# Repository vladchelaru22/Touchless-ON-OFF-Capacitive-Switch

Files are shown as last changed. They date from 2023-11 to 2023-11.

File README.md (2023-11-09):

# Touchless-ON-OFF-Capacitive-Switch
College Project made during CAD Circuit Design class.

Using a given set of parameters, a physical circuit and schematic, I translated the circuit into an OrCAD schematic and produced PCB Design of the circuit using both SMT and THT - using either common PCB Footprints or creating some of my own
Exported the electrical and mechanical layers, with their respective Gerber files, making the project ready to print and fabricate.

Additional information is found in the PDF File (Originally in Romanian-Translation Needed).

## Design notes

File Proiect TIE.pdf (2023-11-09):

## UNIVERSITATEA ,,POLITEHNICA” DIN BUCUREȘTI

Facultatea de Electronică, Telecomunicații și Tehnologia Informației

## Proiect P3 TIE

## Touchless ON/OFF Human Interface Capacitive Switch

DEPARTAMENTUL DE ELECTRONICĂ ȘI TEHNICI DE INTERCONECTARE

Profesor Coordonator:

Prof. Dr. Ing. Norocel Dragoș Codreanu

Echipa T2, studenți:

Cîrstea Georgian-Cristian – Project Manager

Chelaru Vlad-Andrei

Didiță Ana-Maria

An universitar 2022-2023

Dată de predare: 06.09.2023

## CUPRINS

I. DATE INIȚIALE DE PROIECTARE | 3
I.1 Descrierea funcționării schemei proiectate | 4
I.2 Schema electrică | 5
I.3 Design Rules Check(DRC) | 6
I.4 Cross Reference(CR) | 7
I.5 Bill of materials(BOM) | 8
I.6 Wirelist(WR) | 10
I.7 Prezentarea corelației dintre anexa 1 şi proiectul CAD generat | 12
II. PROIECTARE CIRCUIT IMPRIMAT(LAYOUT) - PCB | 13
II.1 Layer-ul TOP | 13
II.2 Layer-ul BOTTOM | 14
II.3 Layer-ul SOLDER MASK TOP | 15
II.4 Layer-ul SOLDER MASK BOTTOM | 16
II.5 Layer-ul SILK SCREEN TOP | 17
II.6 Layer-ul ASSEMBLY DRAWING TOP | 18
III. PROIECTARE MECANICĂ - MECH | 19
III.1 Layer-ul FABRICATION | 19
IV. CONCLUZII | 20
V. BIBLIOGRAFIE/WEBOGRAFIE | 21
VI. ANEXE | 20

# I.Date inițiale de proiectare

Scopul proiectului constă în realizarea design-ului PCB al unui comutator capacitiv ON/OFF fără atingere, conform unei scheme electrice și a unor parametrii dați. O poartă SAU negat 74HC02 acționează ca un senzor capacitiv de mare impedanță. Aceasta setează sau resetează un circuit de blocare și acționează un LED și un releu electromagnetic pentru controlul de înaltă putere. Simpla plasare a unui deget lângă pad este suficientă pentru a comuta latch-ul. Astfel, nu este necesar niciun contact uman, iar pad-ul poate fi izolat. O rază de 15mm este ușor de obținut și sensibilitatea este reglabilă. Alimentarea este furnizată printr-o sursă de 12VDC.

Proiectul PCB va fi realizat utilizând numai două straturi electrice, cele externe: TOP și BOTTOM, toate componentele fiind plasate pe layerul superior al plăcii, TOP. Vor fi folosite și următoarele layer-e neelectrice: SOLDER MASK pentru ambele fețe ale plăcii, SILK SCREEN TOP și ASSEMBLY DRAWING TOP. Lățimea traseelor de semnal va fi de 0.3mm, conexiunea cu masa va fi realizată printr-un plan de masă pe stratul BOTTOM, lățimea traseelor de masă/ alimentare fiind de 1.1mm, iar spațierea va fi de 0.35mm în toate cazurile. Placa va avea formă dreptunghiulară, cu dimensiunile 70x55mm. Cele 4 găuri de prindere a modulului PCB în carcasă vor fi nemetalizate, de 3.2mm diametru, plasate în cele 4 colțuri, la o distanță de 1.5M față de acestea. Aceste specificații și valori de proiectare sunt menționate și in ANEXA 2, pe rândul corespunzător echipei cu numărul 2.

Schema electrică echivalentă în programul OrCAD Capture(va fi prezentată și la sfârșit, în ANEXA 1):

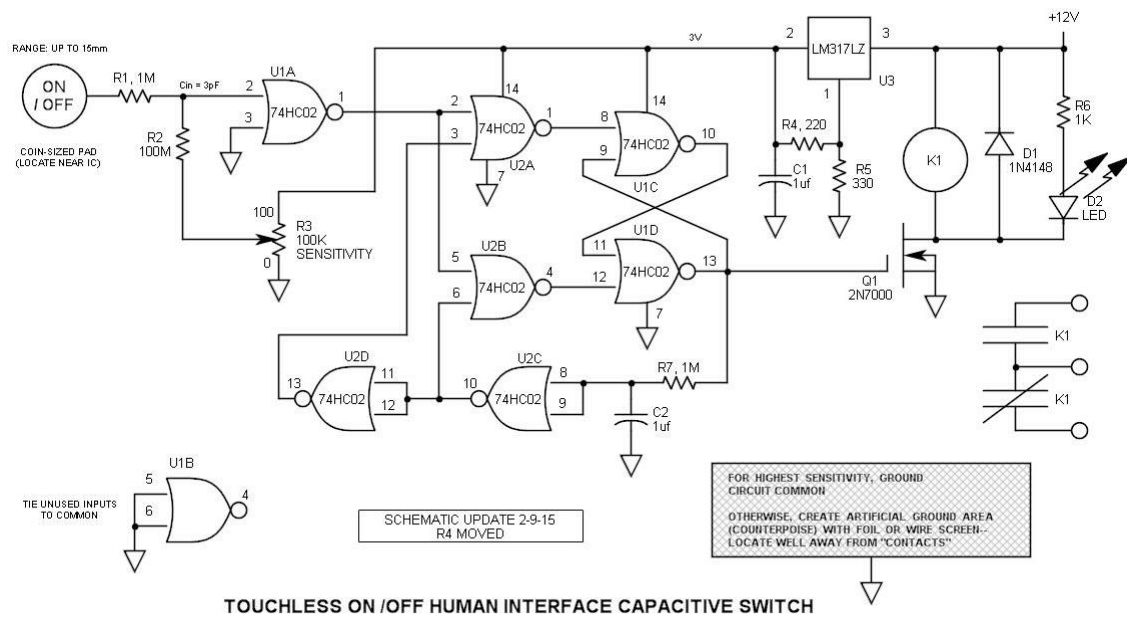
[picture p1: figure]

# I.1 Descrierea funcționării schemei proiectate

Poarta SAU negat 74HC02 acționează ca un senzor capacitiv de mare impedanță, capacitatea de intrare a acesteia fiind de obicei de numai 3pF. Pentru a face acest senzor foarte sensibil la capacitatea corpului este recomandată utilizarea unui resistor de polarizare de 100M.

Sensibilitatea este crescută prin reducerea tensiunii de alimentare la 3V (tensiunea minimă de funcționare specificată fiind de 2.0V). Plasarea unui deget lângă pad este suficientă pentru a comuta latch-ul, nefiind necesar vreun contact uman. Pad-ul, în acest caz, este un ban lipit la un rezistor de 1M. După ce latch-ul este setat sau resetat, condensatorul C2 se încarcă sau se descarcă prin R7. Când se atinge pragul (Vcc/2), porțile U2A și U2B redirecționează semnalul de intrare către intrarea opusă a latch-ului.

Tranzistorul MOS 2N7000 cu canal N (Q1) conduce un curent de 20mA la LED-ul ultraluminos si o tensiune de 12V la releu. Rezistorul de 1M de la intrare protejează circuitul integrat împotriva descărcărilor statice și permite atingerea plăcuței fără pericol de deteriorare prin descărcare electrostatică.

Una dintre problemele apărute pe parcursul evoluției circuitului a fost localizarea porții U2C în U1 din cauza oscilării bruște a U2C când a trecut pragul, generând o perturbare electrică ce a dus la funcționarea defectuoasă a circuitului. De asemenea, o altă problemă a constat în faptul că una dintre intrările porții era deteriorate, probabil din cauza unor descărcări electrostatice, ceea ce împiedicat funcționarea cu impedanță mare.

Cu cât sensibilitatea potențiometrului este mai aproape de prag, cu atât există șanse mai mari ca o perturbare electrostatică sau electromagnetică să provoace accidental schimbări de stare.

## I.2 Schema electrică

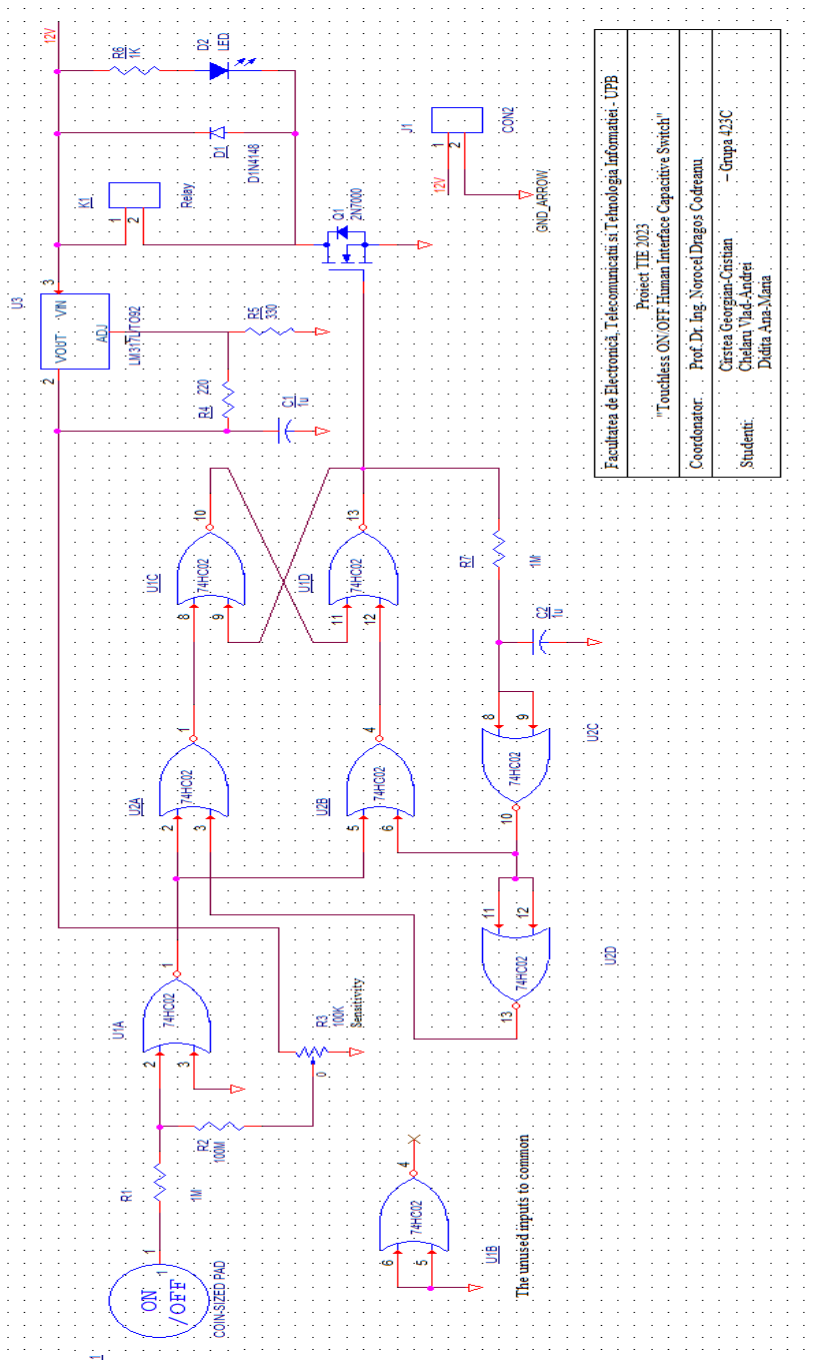
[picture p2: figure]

## I.3 Design Rules Check(DRC)

Date and Time : 09/02/23 17:36:44

Checking Schematic: SCHEMATIC1

Checking Electrical Rules

Checking For Single Node Nets

Checking For Unconnected Bus Nets

## I.4 Cross Reference(CR)

1 | 1K | R6 | SCHEMATIC1/PAGE1 | 0
D:\ORCAD\TOOLS\CAPTURE\LIBRARY\DISCRETE.OLB
2 | 1M | R1 | SCHEMATIC1/PAGE1 | 0
D:\ORCAD\TOOLS\CAPTURE\LIBRARY\DISCRETE.OLB
3 | 1M | R7 | SCHEMATIC1/PAGE1 | 0
D:\ORCAD\TOOLS\CAPTURE\LIBRARY\DISCRETE.OLB
4 | 1u | C1 | SCHEMATIC1/PAGE1 | 0
D:\ORCAD\TOOLS\CAPTURE\LIBRARY\DISCRETE.OLB
5 | 1u | C2 | SCHEMATIC1/PAGE1 | 0
D:\ORCAD\TOOLS\CAPTURE\LIBRARY\DISCRETE.OLB
6 | 2N7000 Q1 | SCHEMATIC1/PAGE1 | 0
D:\ORCAD\TOOLS\CAPTURE\LIBRARY\TRANSISTOR.OLB
7 | 74HC02 U1A | SCHEMATIC1/PAGE1 | 0 | C:\USERS\VLADC\DESKTOP\PROIECT TIE 2023 -
ECHIPA 2 - 423C\CIRCUIT (SCHEMATIC+PCB)\HUMAN_INTERFACE_CAPACITIVE_SWITCH-SCHEMATIC.DSN
8 | 74HC02 U1B | SCHEMATIC1/PAGE1 | 0 | C:\USERS\VLADC\DESKTOP\PROIECT TIE 2023 -
ECHIPA 2 - 423C\CIRCUIT (SCHEMATIC+PCB)\HUMAN_INTERFACE_CAPACITIVE_SWITCH-SCHEMATIC.DSN
9 | 74HC02 U1C | SCHEMATIC1/PAGE1 | 0 | C:\USERS\VLADC\DESKTOP\PROIECT TIE 2023 -
ECHIPA 2 - 423C\CIRCUIT (SCHEMATIC+PCB)\HUMAN_INTERFACE_CAPACITIVE_SWITCH-SCHEMATIC.DSN
10 | 74HC02 U1D | SCHEMATIC1/PAGE1 | 0 | C:\USERS\VLADC\DESKTOP\PROIECT TIE 2023 -
ECHIPA 2 - 423C\CIRCUIT (SCHEMATIC+PCB)\HUMAN_INTERFACE_CAPACITIVE_SWITCH-SCHEMATIC.DSN
11 | 74HC02 U2A | SCHEMATIC1/PAGE1 | 0 | C:\USERS\VLADC\DESKTOP\PROIECT TIE 2023 -
ECHIPA 2 - 423C\CIRCUIT (SCHEMATIC+PCB)\HUMAN_INTERFACE_CAPACITIVE_SWITCH-SCHEMATIC.DSN
12 | 74HC02 U2B | SCHEMATIC1/PAGE1 | 0 | C:\USERS\VLADC\DESKTOP\PROIECT TIE 2023 -
ECHIPA 2 - 423C\CIRCUIT (SCHEMATIC+PCB)\HUMAN_INTERFACE_CAPACITIVE_SWITCH-SCHEMATIC.DSN
13 | 74HC02 U2C | SCHEMATIC1/PAGE1 | 0 | C:\USERS\VLADC\DESKTOP\PROIECT TIE 2023 -
ECHIPA 2 - 423C\CIRCUIT (SCHEMATIC+PCB)\HUMAN_INTERFACE_CAPACITIVE_SWITCH-SCHEMATIC.DSN
14 | 74HC02 U2D | SCHEMATIC1/PAGE1 | 0 | C:\USERS\VLADC\DESKTOP\PROIECT TIE 2023 -
ECHIPA 2 - 423C\CIRCUIT (SCHEMATIC+PCB)\HUMAN_INTERFACE_CAPACITIVE_SWITCH-SCHEMATIC.DSN
15 | 100K | R3 | SCHEMATIC1/PAGE1 | 0
D:\ORCAD\TOOLS\CAPTURE\LIBRARY\PSPICE\BREAKOUT.OLB
16 | 100M | R2 | SCHEMATIC1/PAGE1 | 0
D:\ORCAD\TOOLS\CAPTURE\LIBRARY\DISCRETE.OLB
17 | 220 | R4 | SCHEMATIC1/PAGE1 | 0
D:\ORCAD\TOOLS\CAPTURE\LIBRARY\DISCRETE.OLB
18 | 330 | R5 | SCHEMATIC1/PAGE1 | 0
D:\ORCAD\TOOLS\CAPTURE\LIBRARY\DISCRETE.OLB
19 | COIN-SIZED PAD 1 | SCHEMATIC1/PAGE1 | 0 | C:\USERS\VLADC\DESKTOP\PROIECT
TIE-HUMAN INTERFACE CAPACITIVE SWITCH\HUMAN_INTERFACE_CAPACITIVE_SWITCH-SCHEMATIC.DSN
20 | CON2 | J1 | SCHEMATIC1/PAGE1 | 0 | C:\USERS\VLADC\DESKTOP\PROIECT TIE 2023 -
ECHIPA 2 - 423C\CIRCUIT (SCHEMATIC+PCB)\HUMAN_INTERFACE_CAPACITIVE_SWITCH-SCHEMATIC.DSN
21 | D1N4148D1 | SCHEMATIC1/PAGE1 | 0
D:\ORCAD\TOOLS\CAPTURE\LIBRARY\PSPICE\EDIODE.OLB
22 | LED | D2 | SCHEMATIC1/PAGE1 | 0
D:\ORCAD\TOOLS\CAPTURE\LIBRARY\DISCRETE.OLB
23 | LM317L/TO92 | U3 | SCHEMATIC1/PAGE1 | 0 | C:\USERS\VLADC\DESKTOP\PROIECT
TIE 2023 - ECHIPA 2 - 423C\CIRCUIT (SCHEMATIC+PCB)\HUMAN_INTERFACE_CAPACITIVE_SWITCH-SCHEMATIC.DSN
24 | Relay | K1 | SCHEMATIC1/PAGE1 | 0
D:\ORCAD\TOOLS\CAPTURE\LIBRARY\CONNECTOR.OLB

I.5 Bill Of Materials(BOM) | Pret total: 56.55 lei

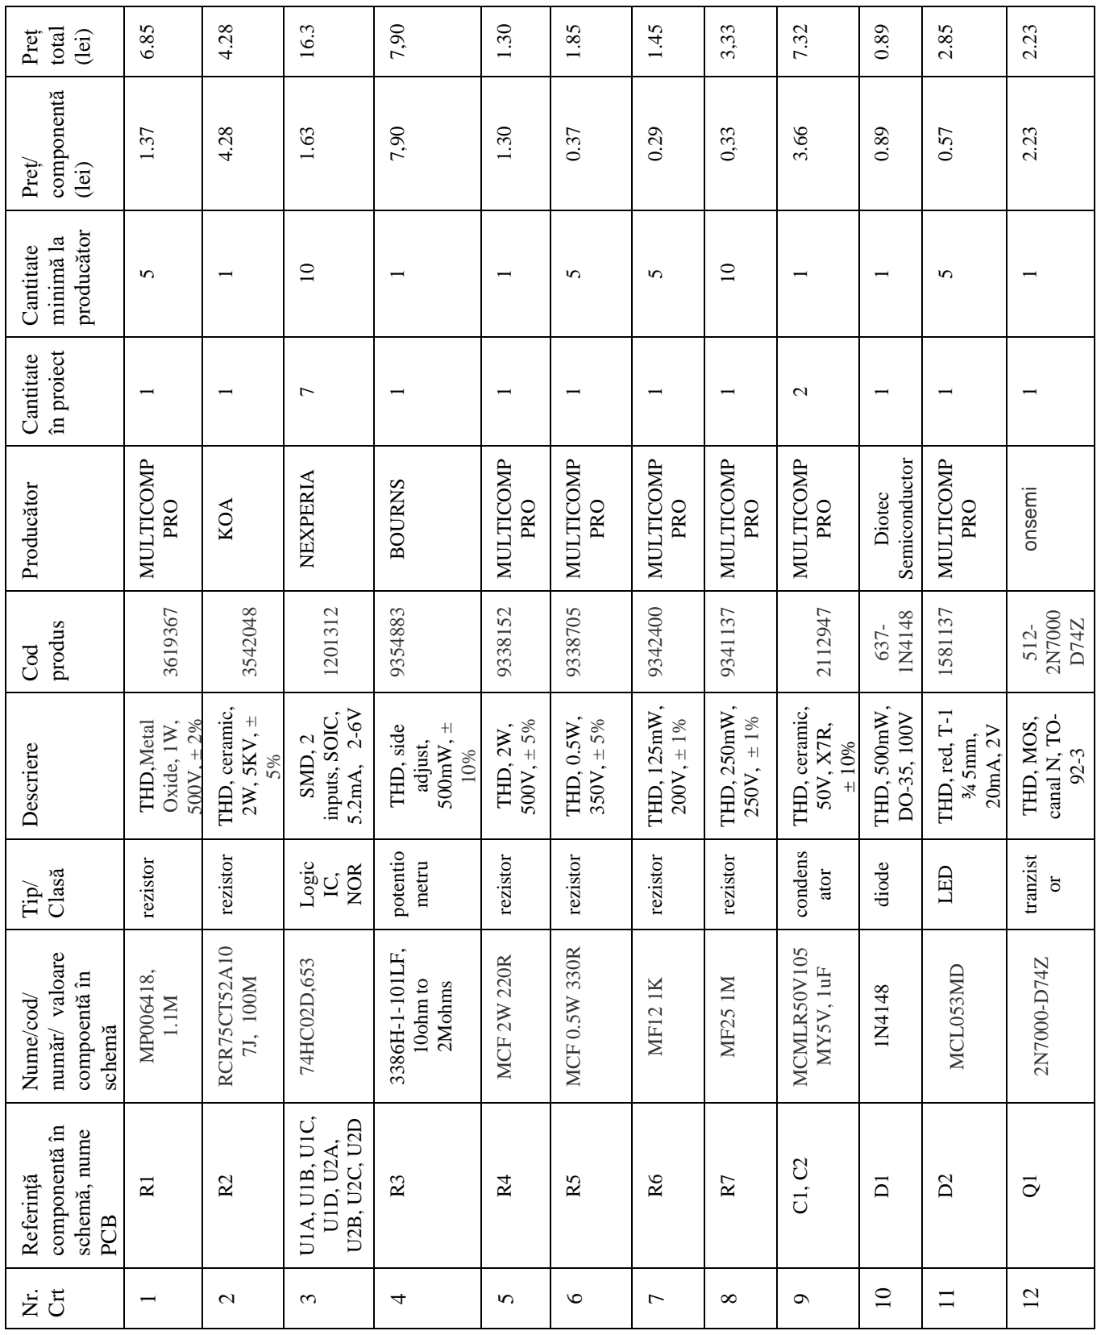
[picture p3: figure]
Preț; total; (lei); Preț/; componentă; Cantitate; minimă la; producător; în proiect; Producător; MULTICOMP; PRO; KOA; NEXPERIA; BOURNS; Diotec; Semiconductor; onsemi; Cod; produs; Descriere; THD,Metal; Oxide, 1W,; THD, ceramic,; SMD, 2; inputs, SOIC,; THD, side; adjust,; THD, 2W,; THD, 0.5W,; THD, 125mW,; THD, 250mW,; THD, 500mW,; THD, red, T-1; THD, MOS,; canal N, TO- 92-3; Tip/; Clasă; rezistor; Logic; NOR; gate; potentio; metru; condens; ator; diode; LED; tranzist; Nume/cod/; număr/ valoare; compoentă în; schemă; RCR75CT52A10; 10ohm to; 2Mohms; MCF 2W 220R; MCF 0.5W 330R; MCMLR50V105; MCL053MD; Referinţă; componentă în; schemă, nume; PCB; Crt

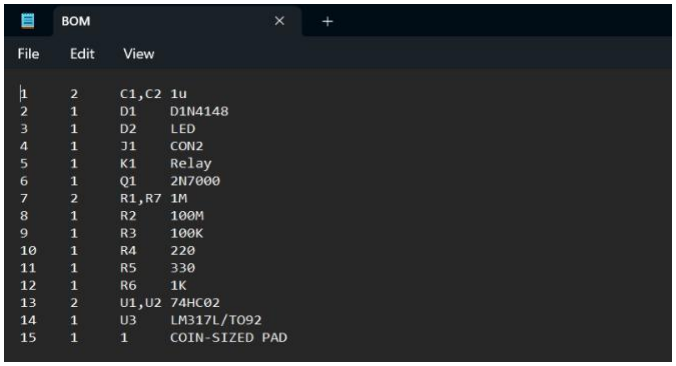
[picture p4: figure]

1 | 2 | C1,C2 1u
2 | 1 | D1 | D1N4148
3 | 1 | D2 | LED
4 | 1 | J1 | CON2
5 | 1 | K1 | Relay
6 | 1 | Q1 | 2N7000
7 | 2 | R1,R7 1M
8 | 1 | R2 | 100M
9 | 1 | R3 | 100K
10 | 1 | R4 | 220
11 | 1 | R5 | 330
12 | 1 | R6 | 1K
13 | 2 | U1,U2 74HC02
14 | 1 | U3 | LM317L/TO92
15 | 1 | 1 | COIN-SIZED PAD

## I.6 Wirelist(WR)

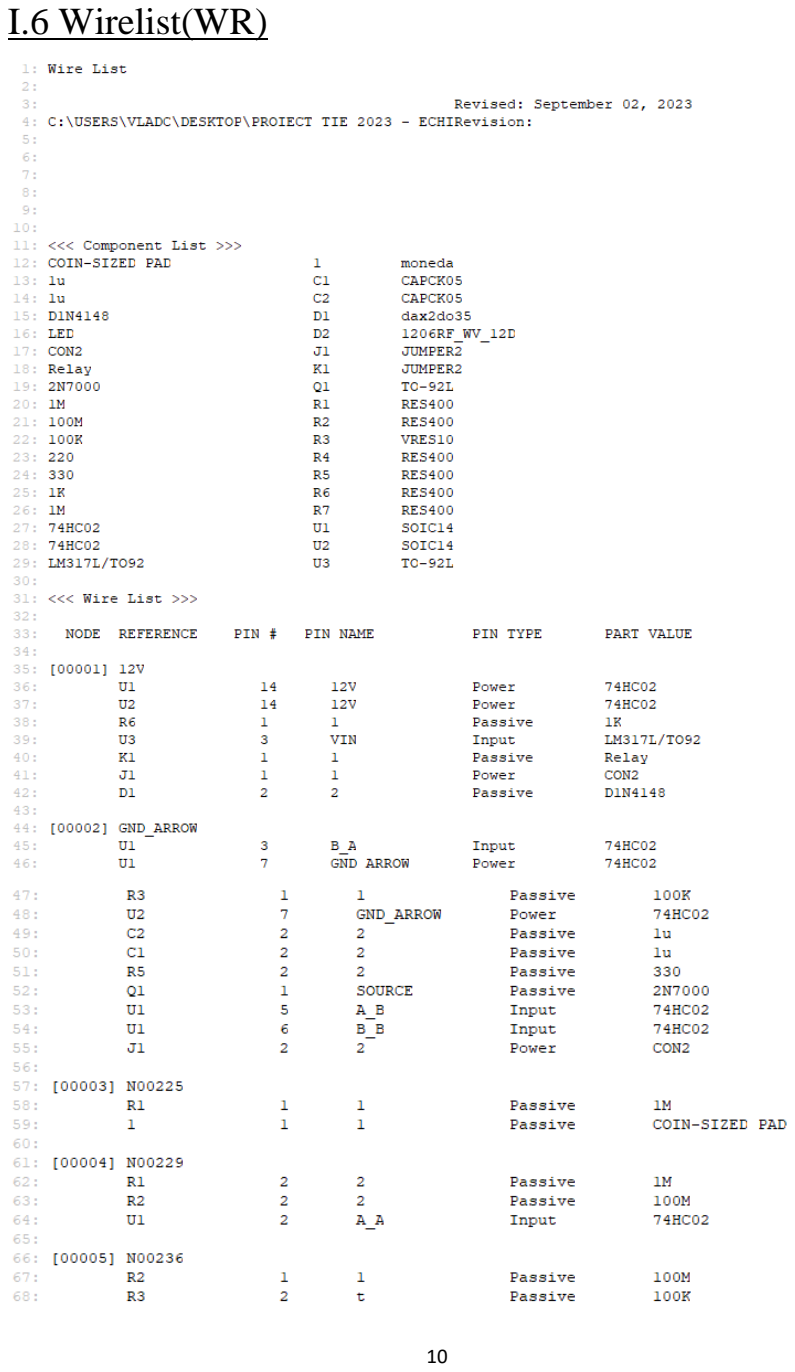
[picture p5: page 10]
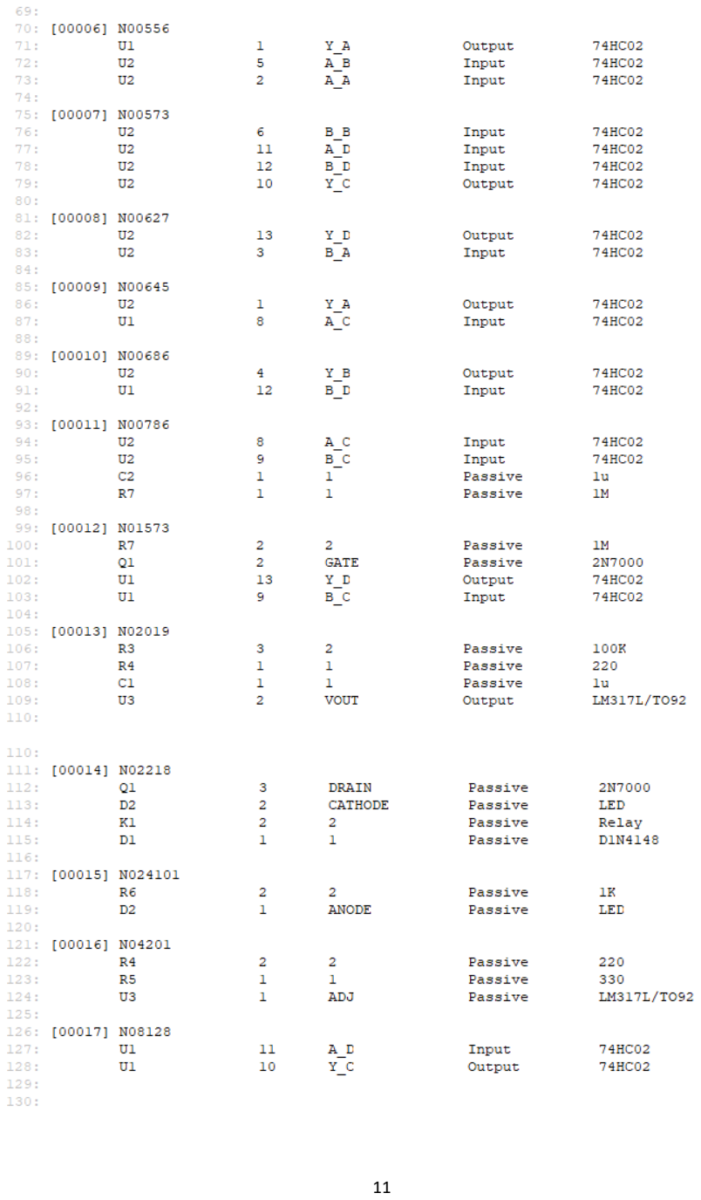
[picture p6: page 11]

## I.7 Prezentarea corelației dintre anexa 1 şi proiectul CAD generat

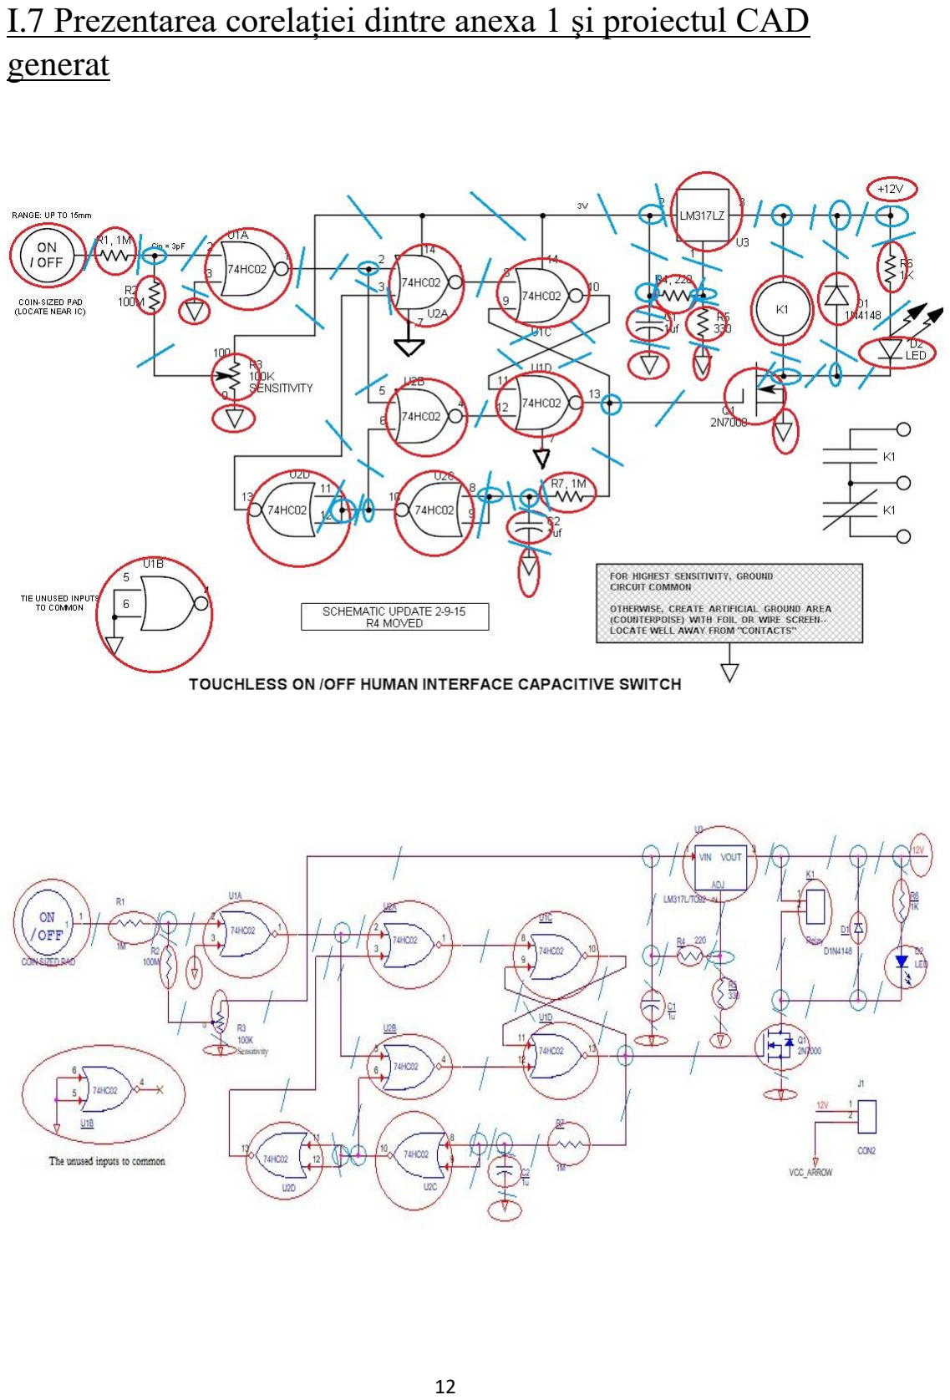
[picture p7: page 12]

# II. PROIECTARE CIRCUIT IMPRIMAT(LAYOUT) – PCB

## II.1 Layer-ul TOP

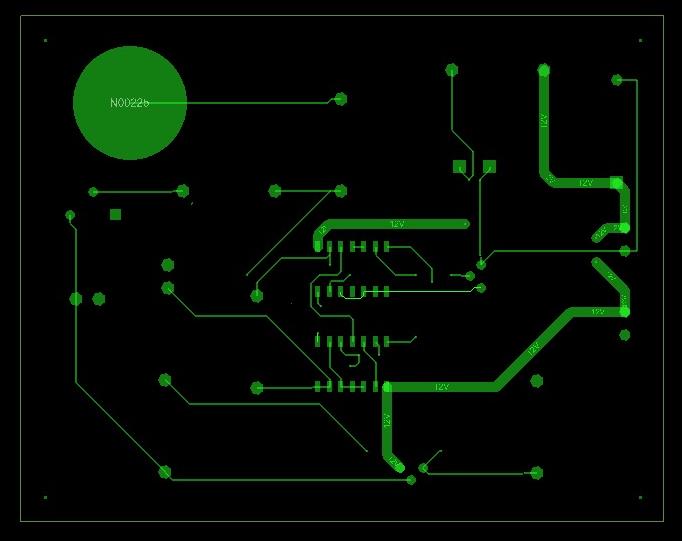
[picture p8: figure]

## II.2 Layer-ul BOTTOM

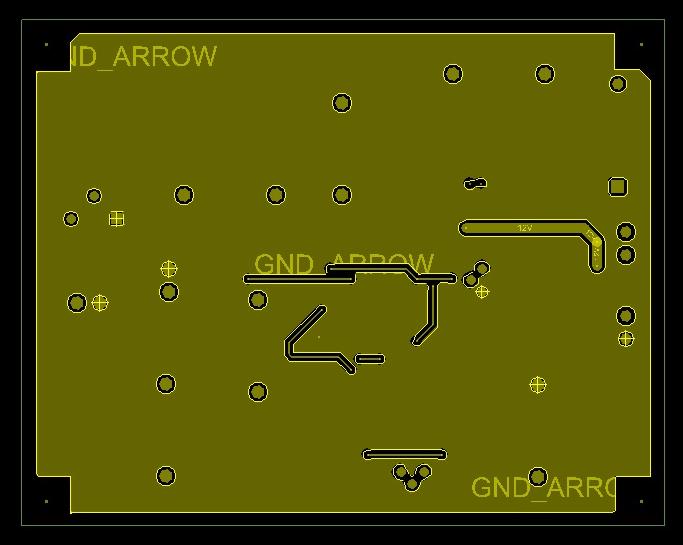
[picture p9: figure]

## II.3 Layer-ul SOLDER MASK TOP

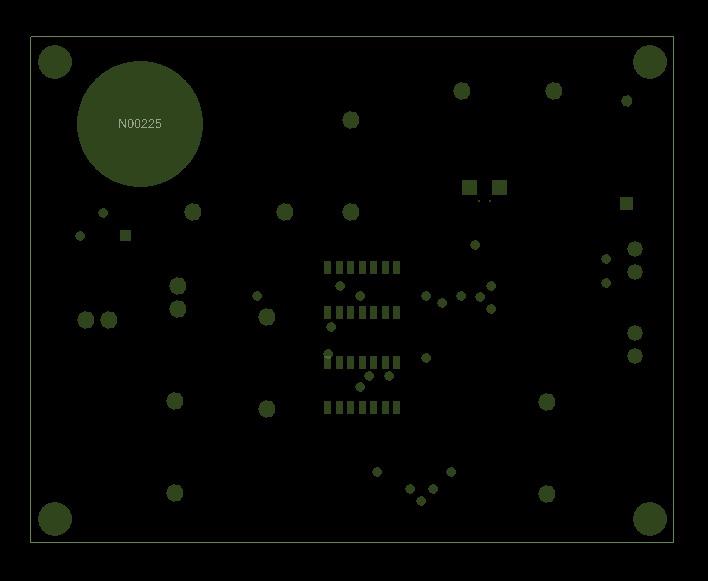
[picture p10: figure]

## II.4 Layer-ul SOLDER MASK BOTTOM

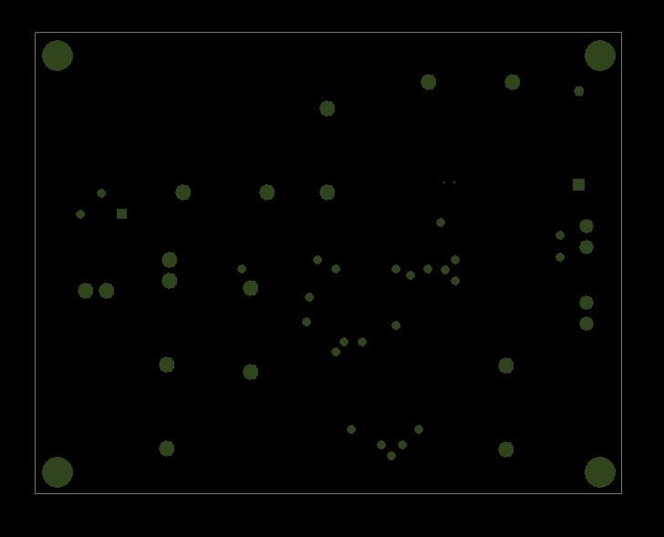
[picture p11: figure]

## II.5 Layer-ul SILK SCREEN TOP

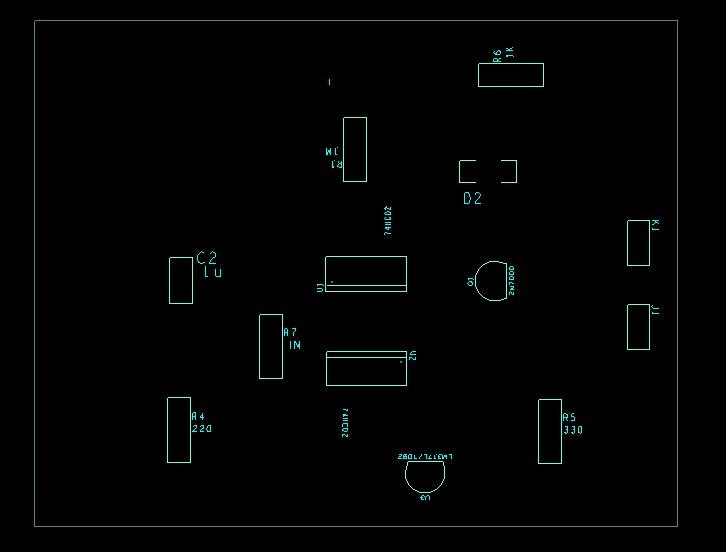
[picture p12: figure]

## II.6 Layer-ul ASSEMBLY DRAWING TOP

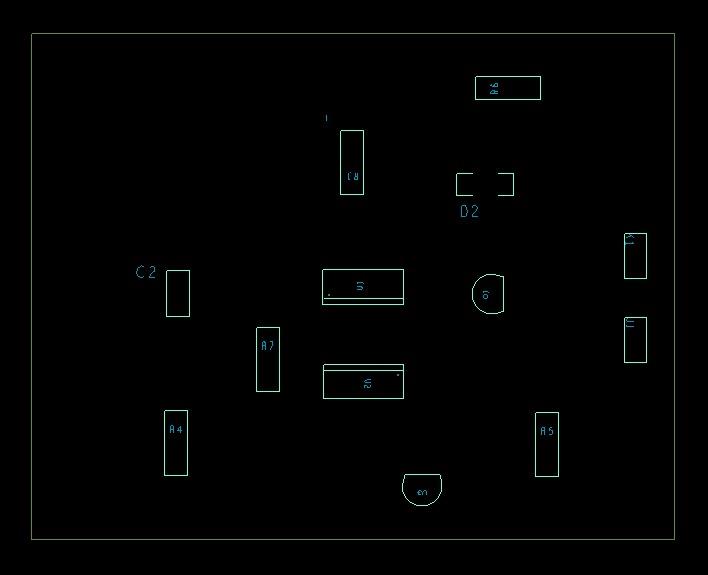
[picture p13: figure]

# III. PROIECTARE MECANICĂ - MERCH

## III.1 Layer-ul FABRICATION

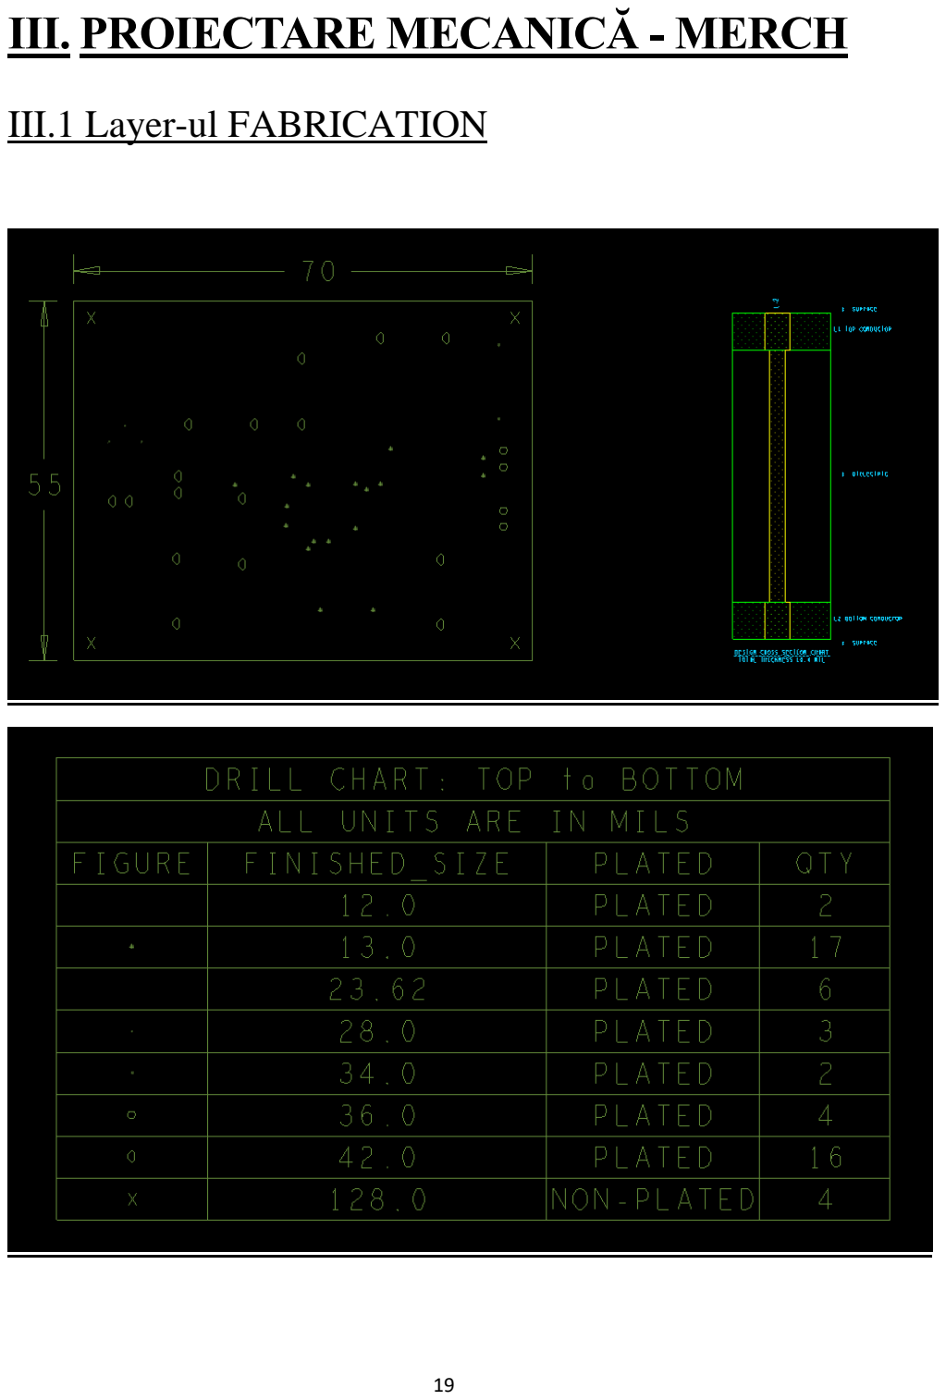
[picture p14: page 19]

# IV. CONCLUZII

Pentru proiectarea structurii schematice a acestui modul electronic a fost utilizat programul OrCAD 17.2 Lite, iar elaborarea design-ului PCB a fost realizată prin intermediul programului OrCAD PCB Editor. Deși acestea ne oferă o multitudine de facilități în realizarea, verificarea si simularea diverselor scheme electrice, este necesară și atenția la detalii pentru a efectua toate operațiile necesare procesării, fără a întâmpina defecte de proiectare ce duc la funcționarea defectuoasă a circuitului. Prin înțelegerea funcționalității schemei ce urmează a fi proiectată se pot evita aceste erori, se pot reduce costurile suplimentare și se poate economisi timp.

Realizarea acestei lucrări ne-a oferit posibilitatea de a înțelege importanța proiectării PCB, reușind să căpătăm cunoștințele și abilitățile de bază absolut necesare pe care trebuie să le îndeplinească un proiectant de success.

# V. BIBLIOGRAFIE/WEBOGRAFIE

1. https://www.electroschematics.com/touchless-on-off-capacitive-switch/
2. https://youtu.be/mjoHTE26fHQ
3. https://ro.farnell.com/
4. https://ro.mouser.com/

# VI. ANEXE

## ANEXA 1

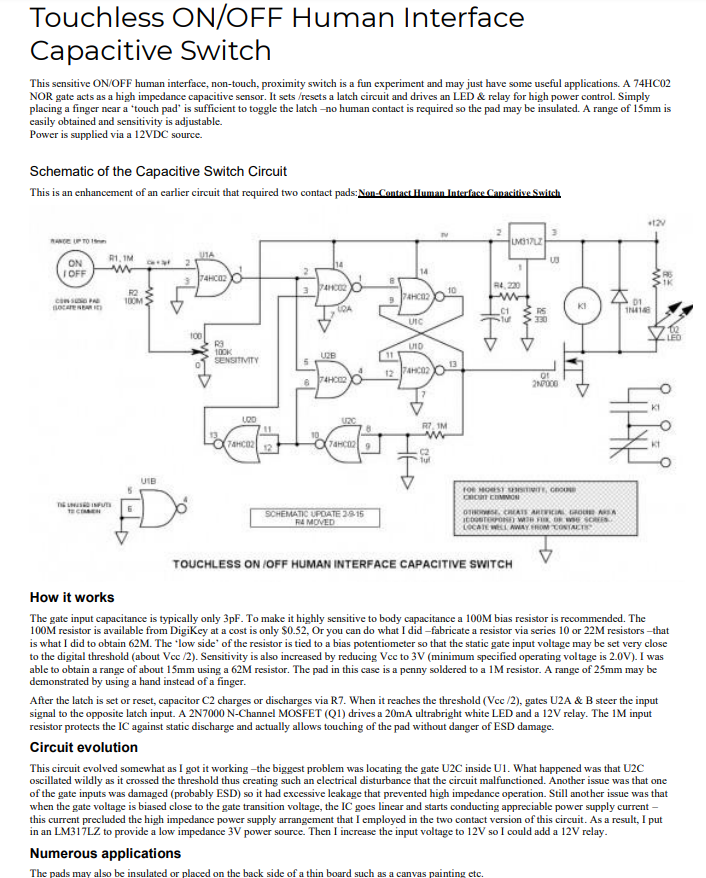
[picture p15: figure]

## ANEXA 2

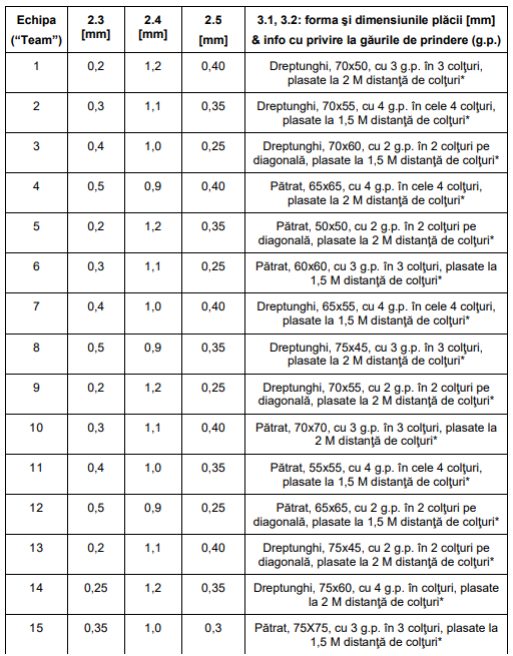
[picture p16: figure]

## ANEXA 3

Nr. crt. | Link
1. https://ro.farnell.com/multicomp-pro/mp006418/res-1m1-1w-axial-metal- | oxide/dp/3619367 (https://ro.farnell.com/multicomp-pro/mp006418/res-1m1-1w-axial-metal-oxide/dp/3619367)
2. https://ro.farnell.com/koa-speer-electronics/rcr75ct52a107j/res-100m-2w-axial- | ceramic/dp/3542048 (https://ro.farnell.com/koa-speer-electronics/rcr75ct52a107j/res-100m-2w-axial-ceramic/dp/3542048)
3. https://ro.farnell.com/nexperia/74hc02d/ic-logic-nor-14soic/dp/1201312?st=74HC02
4. https://ro.farnell.com/bourns/3386h-1-101lf/trimmer-pot-100-ohm-10-1turn- | th/dp/9354883 (https://ro.farnell.com/bourns/3386h-1-101lf/trimmer-pot-100-ohm-10-1turn-th/dp/9354883)
5. https://ro.farnell.com/multicomp/mcf-2w-220r/res-220r-5-2w-axial-carbon- | film/dp/9338152?ost=mcf+2w+220r (https://ro.farnell.com/multicomp/mcf-2w-220r/res-220r-5-2w-axial-carbon-film/dp/9338152?ost=mcf+2w+220r)
6. https://ro.farnell.com/multicomp/mcf-0-5w-330r/res-330r-5-500mw-axial- | carbon/dp/9338705?ost=mcf+0.5w+330r (https://ro.farnell.com/multicomp/mcf-0-5w-330r/res-330r-5-500mw-axial-carbon/dp/9338705?ost=mcf+0.5w+330r)
7. https://ro.farnell.com/multicomp/mf12-1k/res-1k-1-125mw-axial-metal- | film/dp/9342400?st=mf12%201k (https://ro.farnell.com/multicomp/mf12-1k/res-1k-1-125mw-axial-metal-film/dp/9342400?st=mf12%201k)
8. https://ro.farnell.com/multicomp/mf25-1m/res-1m-1-250mw-axial-metal- | film/dp/9341137?ost=mf25+1m (https://ro.farnell.com/multicomp/mf25-1m/res-1m-1-250mw-axial-metal-film/dp/9341137?ost=mf25+1m)
9. https://ro.farnell.com/multicomp/mcmlr50v105kx7r/cap-1-f-50v-10- | x7r/dp/2112947?st=1uF (https://ro.farnell.com/multicomp/mcmlr50v105kx7r/cap-1-f-50v-10-x7r/dp/2112947?st=1uF)
10 | https://ro.mouser.com/ProductDetail/Diotec-Semiconductor/1N4148?qs=OlC7AqGiEDmWf1%2FPHy84oA%3D%3D (https://ro.mouser.com/ProductDetail/Diotec-Semiconductor/1N4148?qs=OlC7AqGiEDmWf1%2FPHy84oA%3D%3D)
11. https://ro.farnell.com/multicomp/mcl053md/led-5mm-36-he- | red/dp/1581137?st=diode%20led%20thru%20hole (https://ro.farnell.com/multicomp/mcl053md/led-5mm-36-he-red/dp/1581137?st=diode%20led%20thru%20hole)
12. https://ro.mouser.com/ProductDetail/onsemi-Fairchild/2N7000- | D74Z?qs=0lQeLiL1qyY5n6GYLOSgWQ%3D%3D (https://ro.mouser.com/ProductDetail/onsemi-Fairchild/2N7000-D74Z?qs=0lQeLiL1qyY5n6GYLOSgWQ%3D%3D)

*Nr. Crt. de la fiecare link corespunde cu Nr. crt. din tabelul BOM de la pagina 8.

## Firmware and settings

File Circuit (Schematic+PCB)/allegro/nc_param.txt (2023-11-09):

INTEGER-PLACES         2
DECIMAL-PLACES         5
X-OFFSET               0.000000
Y-OFFSET               0.000000
FEEDRATE               1
COORDINATES            ABSOLUTE
OUTPUT-UNITS           ENGLISH
TOOL-ORDER             INCREASING
REPEAT-CODES           YES
SUPPRESS-LEAD-ZEROES   NO
SUPPRESS-TRAIL-ZEROES  NO
SUPPRESS-EQUAL         NO
TOOL-SELECT            NO
OPTIMIZE_DRILLING      NO
ENHANCED_EXCELLON      NO
HEADER                 none
LEADER                 12
CODE                   ASCII
SEPARATE               NO
SEPARATE-ROUTING       NO
DRILLING               LAYER-PAIR
BACKDRILL              NO
COUNTER                NO
CAVITY                 NO
TOLERANCE_DRILL        YES
TOLERANCE_TRAVEL       YES
TOOL_SIZE              YES
ROTATION               YES
NON_STANDARD           YES
TOTAL_DRILL            NO
SEPARATE_SLOT          NO
SUPPRESS_TOLERANCE     YES
SUPPRESS_TOOLSIZE      YES
SUPPRESS_ROTATION      YES

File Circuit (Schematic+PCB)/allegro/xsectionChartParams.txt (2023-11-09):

CHART_UNIT Mils
LAYER_NAME YES
LAYER_THICKNESS YES
LAYER_THICKNESS_TOL YES
MATERIAL_NAME YES
EMB_STATUS YES
ATTACH_METHOD YES
LAYER_TYPE YES
DRILL_SPAN YES
BACKDRILL_SPAN YES
STACKED_VIAS YES
EMD_COMP_LEGEND  YES
DRILL_LABEL  YES
X_SCALE_FACTOR  1.000
DIELECTRIC_SCALE_FACTOR  300.000
TEXT_BLOCK  1
MAX_CHART_HEIGHT 2402.4 MIL
